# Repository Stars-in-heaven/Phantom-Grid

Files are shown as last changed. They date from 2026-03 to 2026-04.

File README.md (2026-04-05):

# PHANTOM GRID

> *Offline-first. Air-gapped. Encrypted. Built for the field.*

Phantom Grid is a series of purpose-built handheld devices engineered for those who operate outside the comfort of connectivity. No Wi-Fi. No cloud sync. No IP assignment. Every hardware and firmware decision is governed by a single principle: **security first, convenience never.**

https://phantom-grid.netlify.app - our site :0 **( has some issues/WIP cuz I keep running out of Netlify credit )**

---

## Series

| ID | Name | Description |
|----|---|---|
| **S** | Survival | Bare minimum. Maximum efficiency. Built to run when nothing else does. |
| **T** | Tactical | Feature-packed, encrypted, hardened. Heavy-duty field use. |
| **X** | Experimental | Highly specialised. Each unit unique. Not for general deployment. |
| **C** | Cyber | Fully off-grid. Offensive posture. Maximum resource load. |

---

## Current Build — T-V.1

The first Tactical series device. Dual-panel, hinged form factor with three independent displays, local sensor data, GPS, and an air-gapped file archive terminal.

### Architecture

- **Dual ESP32-C6 SuperMini** — one per side, connected via 4-wire UART hinge link
- **Left side** — Tactical Overwatch Panel (OLEDs, 5-way nav, GPS, moisture, battery)
- **Right side** — Archive Command Terminal (ILI9341 TFT, microSD, tactile buttons)
- **Power** — LiPo 2000–2500mAh → TP4056 (dual protection) → 3.3V buck converter → shared rail via hinge

### Displays

| Display | Role | Interface |
|---|---|---|
| 0.91" OLED 128×32 | Battery, time, date | I²C |
| 1.5" OLED 128×128 | GPS, moisture, sensor data | I²C via TCA9548A |
| 2.4" TFT ILI9341 | File browser, archive terminal | SPI |

### Storage

Files are loaded onto the microSD card by **physically removing it**, writing via USB adapter on a separate machine, and reinserting. No cloud sync. No Wi-Fi. No detectable radio signature. By design.

---

## Build Phases

- [x] **Phase 1** — Architecture & Pinout
- [x] **Phase 2** — Breadboard Prototype
- [ ] **Phase 3** — Firmware Foundation
- [x] **Phase 4** — Feature Layer
- [ ] **Phase 5** — Firmware Hardening
- [ ] **Phase 6** — Physical Build

 (working on getting the components to build the first
  prototype to begin firmware)

---

## Firmware Protection (Phase 5)

- Strip all debug symbols, aggressive optimisation (`-O2/-O3`)
- Obfuscator-LLVM control flow mangling
- CRC/hash self-check on boot — halts if tampered
- Chip ID binding — binds to first chip it runs on, cloning breaks it
- Sensitive logic derived at runtime, never stored plainly in binary
- Binary-only distribution with checksum and signature

---

## Repository Structure

```
phantom-grid/
├── Enclosure/               # Case 3d model
│   ├── Enclosure.f3d
│   ├── Enclosure.step
│   └── Enclosure.stl
|
├── PCBs/               # Kicad PCB files
│   ├── left side/
|   |    ├── left_side.kicad_pcb
|   |    ├── left_side.kicad_pro
|   |    └── left_side.kicad_sch
|   |
│   └── right side/
|       ├── right.kicad_pcb
|       ├── right.kicad_pro
|       └── right.kicad_sch
|  
├── .gitignore
├── README.md    
└── LICENSE

```

---

## Estimated Build Cost

**~£43–80** depending on component sourcing. All parts sourced from AliExpress. Full BOM available in `site/bom.html`.

---

## Progress --  T-V.1

### Left side ( Tactical over-watch Panel )
| Schematic | PCB | 3d-view  |
| --- |:---:| -----:|
|  |  |  |

### Right side ( Archive Terminal Panel )
| Schematic | PCB | 3d-view  |
| --- |:---:| -----:|
|  |  |  |

### ENCLOSURE:
 (It is split in half, but due to this being a prototype it has no screw holes, As I plan to drill them in for testing sizes and such. And then in more final models it will advance to having screw holes.)

---

## Licensing

This project uses a dual licensing model:

| What | Licence | Details |
|---|---|---|
| PCB files, enclosure, skeleton firmware | **CERN-OHL-S v2** | Open hardware — modifications must be released under the same licence |
| Full feature firmware | **Proprietary** | Never released — binary only, chip-bound, encrypted |

The open skeleton gives you everything you need to understand how the device is wired and structured. The full firmware with all features ships only with commercially built units and is protected by hardware-level encryption and chip binding. You are free to build your own version using the open source materials — you cannot take the commercial firmware.

---

*PG-T-V.1 / REV.002 / ENCRYPTED / AIR-GAPPED*

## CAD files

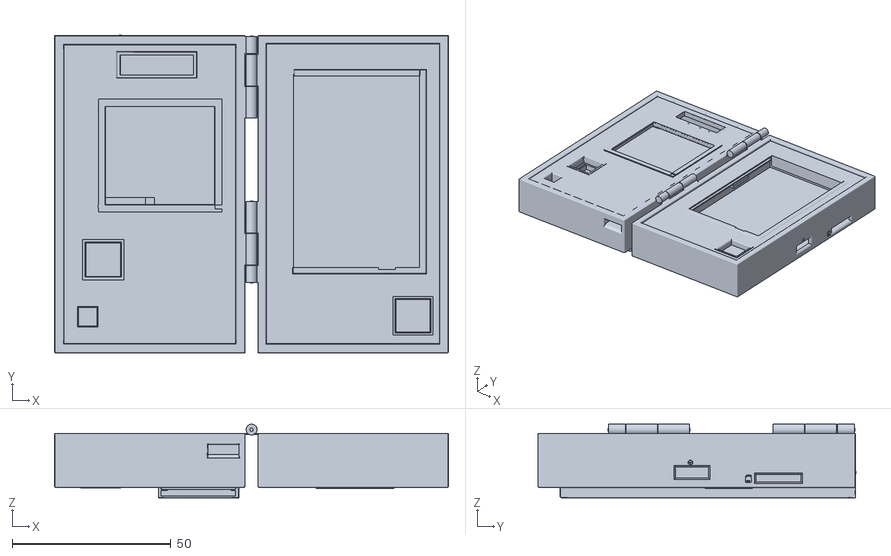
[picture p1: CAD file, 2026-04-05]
Enclosure/Enclosure.stl
124.0 x 100.1 x 23.2

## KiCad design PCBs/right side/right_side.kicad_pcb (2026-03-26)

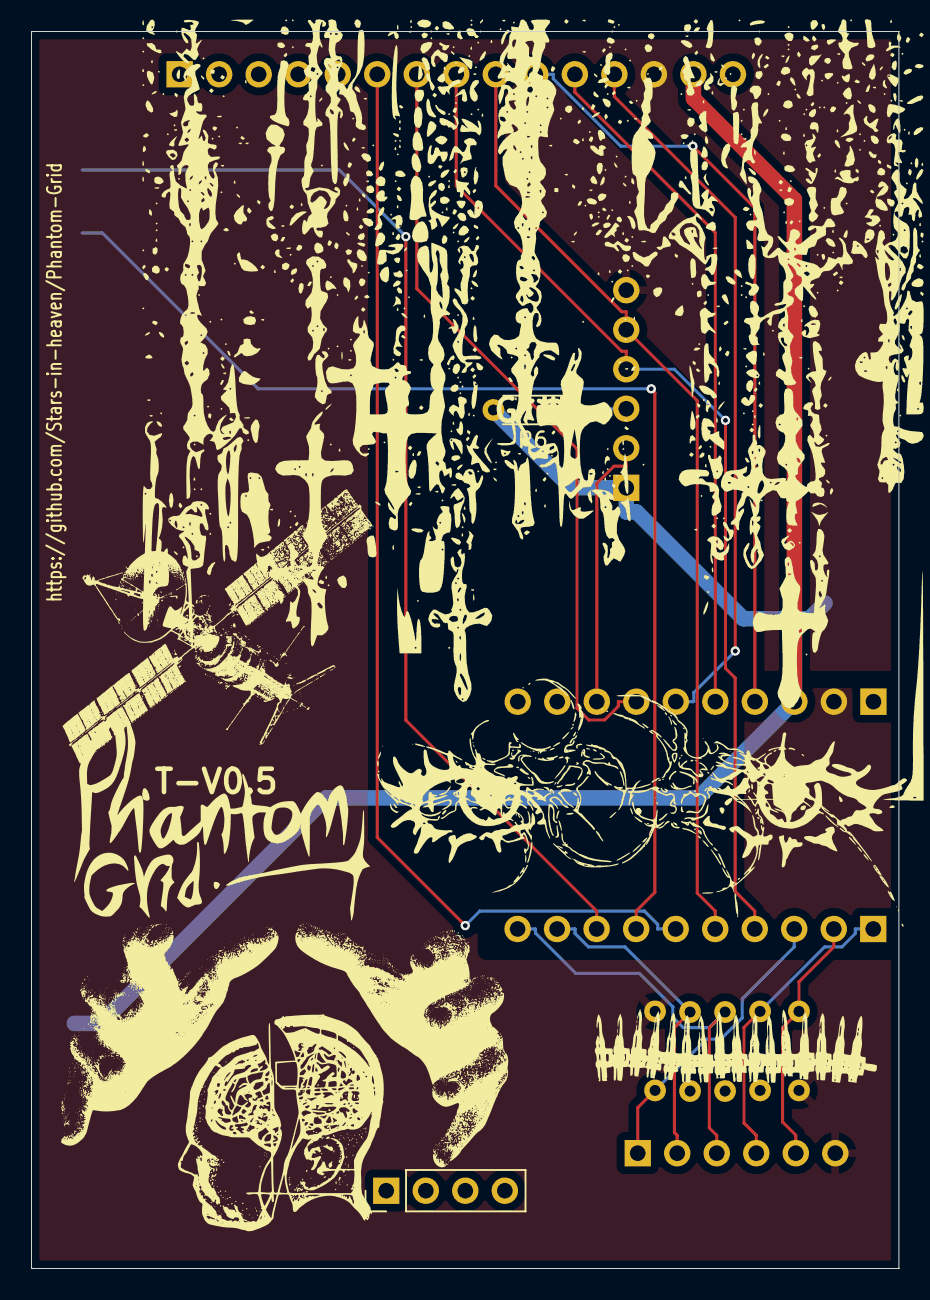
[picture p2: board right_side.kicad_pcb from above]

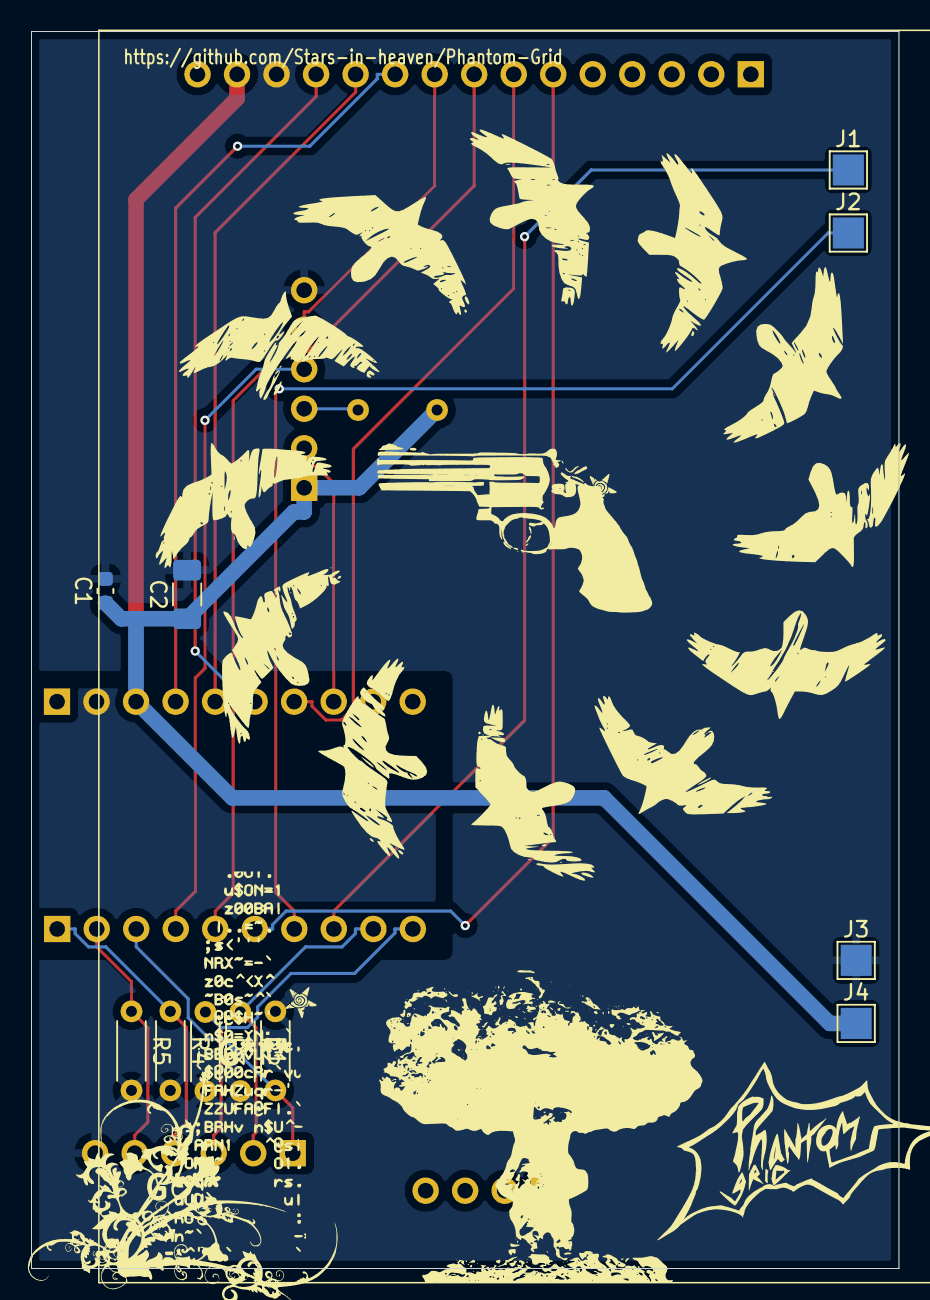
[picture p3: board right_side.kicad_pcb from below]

Board: 2 copper layers, 55.8 x 79.5 mm, 18 parts (13 on the bottom side), 18 nets.

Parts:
5-way_nav1: 5 way
.: LOGO
C1: 100nF; C_0603_1608Metric
C2: 10uF; C_1206_3216Metric_Pad1.33x1.80mm_HandSolder
J1: TX HINGE; TestPoint_Pad_2.0x2.0mm
J2: RX HINGE; TestPoint_Pad_2.0x2.0mm
J3: GND HINGE; TestPoint_Pad_2.0x2.0mm
J4: 3V3 HINGE; TestPoint_Pad_2.0x2.0mm
J5: TFT screen; PinHeader_1x15_P2.54mm_Vertical
J7: SD READER; PinHeader_1x06_P2.54mm_Vertical
R1, R2, R3, R4, R5: 10k; R_Axial_DIN0204_L3.6mm_D1.6mm_P5.08mm_Horizontal
R6: 10K; R_Axial_DIN0204_L3.6mm_D1.6mm_P5.08mm_Horizontal
U1: ESP32-C6 MINI
logo 2: LOGO

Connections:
+3V3: C1.1, C2.1, J4.1, J5.14, J7.1, R6.2, U1.13 (3V3)
/HINGE_RX: J2.1, U1.7 (GPIO_04)
/HINGE_TX: J1.1, U1.8 (GPIO_05)
GND: 5-way_nav1.6 (gnd), C1.2, C2.2, J3.1, J5.13, J7.6, R1.2, R2.2, R3.2, R4.2, R5.2, U1.12 (GND)
SD_CS: J7.2, U1.18 (GPIO_10)
SD_MISO: J7.3, R6.1
TFT_CLK: J5.8, J7.4, U1.4 (GPIO_01)
TFT_CS: J5.12, U1.16 (GPIO_21)
TFT_DC: J5.10, U1.14 (GPIO_19)
TFT_LED: J5.7, U1.17 (GPIO_22)
TFT_MISO: J5.6, U1.6 (GPIO_03)
TFT_MOSI: J5.9, J7.5, U1.5 (GPIO_02)
TFT_RST: J5.11, U1.15 (GPIO_20)
back_1: 5-way_nav1.2 (back), R2.1, U1.9 (GPIO_06)
forward_1: 5-way_nav1.1 (forward), R1.1, U1.3 (GPIO_00)
left_1: 5-way_nav1.3 (left), R3.1, U1.10 (GPIO_07)
middle_1: 5-way_nav1.5 (m), R5.1, U1.2 (RX)
right_1: 5-way_nav1.4 (right), R4.1, U1.1 (TX)

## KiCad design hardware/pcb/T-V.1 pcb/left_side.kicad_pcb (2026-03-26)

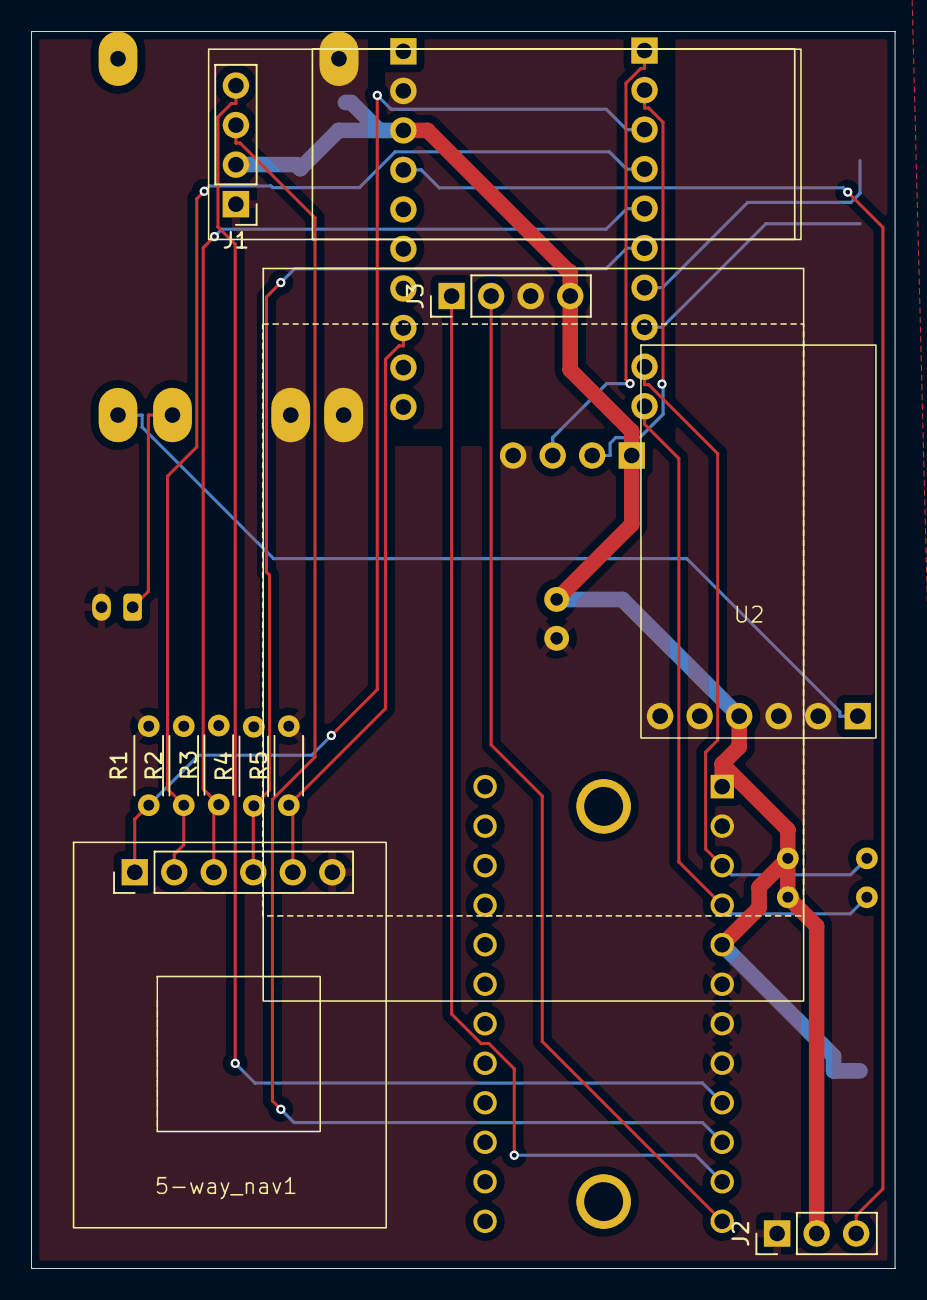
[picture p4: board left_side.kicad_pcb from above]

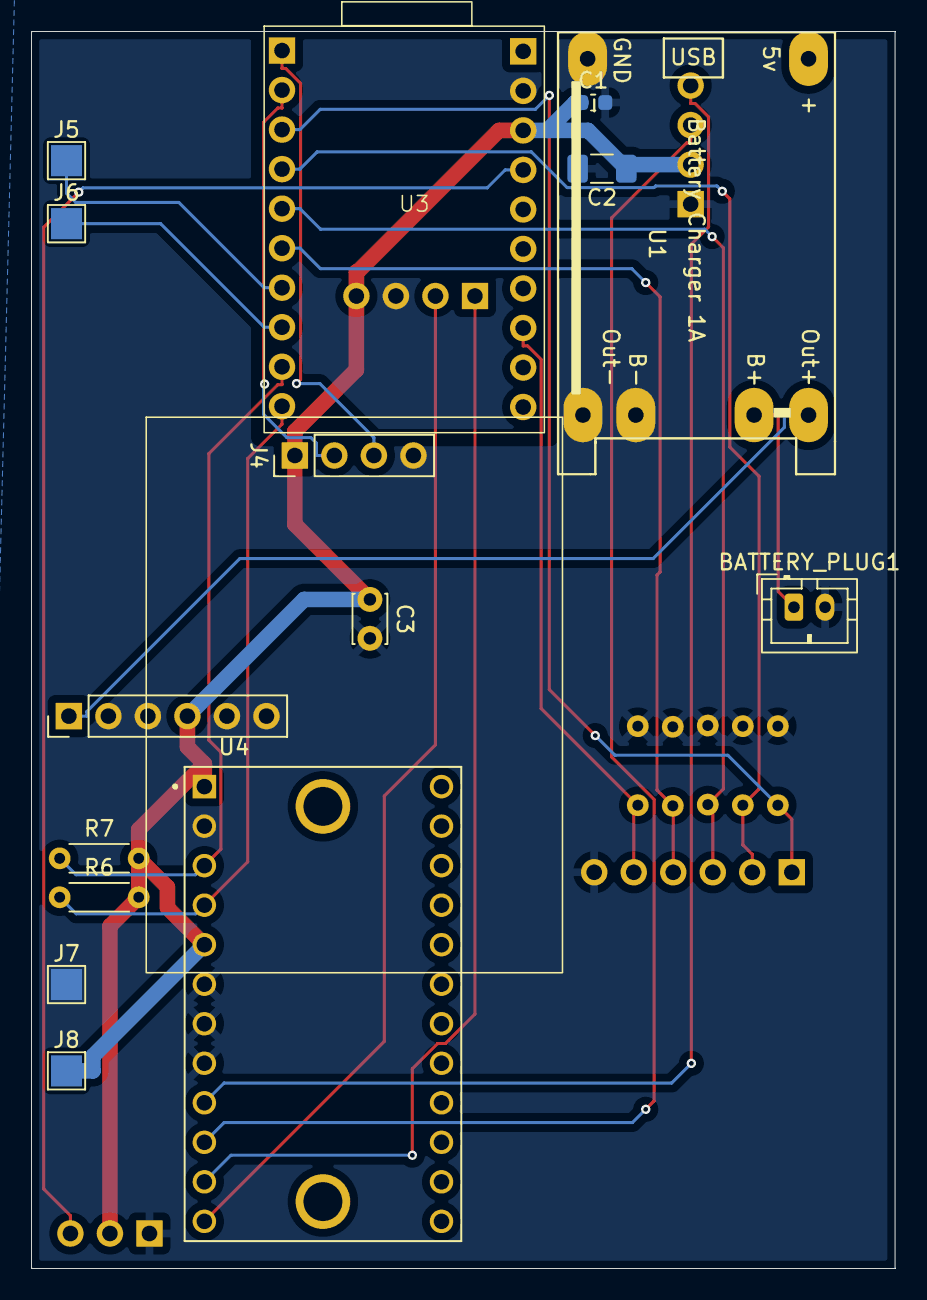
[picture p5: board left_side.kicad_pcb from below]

Board: 2 copper layers, 55.5 x 79.5 mm, 24 parts (14 on the bottom side), 20 nets.

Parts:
5-way_nav1: 5 way
BATTERY_PLUG1: B2B-PH-K-S_LF__SN_; JST_PH_B2B-PH-K_1x02_P2.00mm_Vertical
C1: 100nF; C_0603_1608Metric
C2: 10uF; C_1206_3216Metric_Pad1.33x1.80mm_HandSolder
C3: 100nF; C_Disc_D3.0mm_W2.0mm_P2.50mm
J1: MINI oled; PinHeader_1x04_P2.54mm_Vertical
J2: Moisture sensor; PinHeader_1x03_P2.54mm_Vertical
J3: MAIN oled; PinHeader_1x04_P2.54mm_Vertical
J4: GPS; PinHeader_1x04_P2.54mm_Vertical
J5: TX HINGE; TestPoint_Pad_2.0x2.0mm
J6: RX HINGE; TestPoint_Pad_2.0x2.0mm
J7: GND HINGE; TestPoint_Pad_2.0x2.0mm
J8: 3V3 HINGE; TestPoint_Pad_2.0x2.0mm
R1, R2, R3, R4, R5: 10k; R_Axial_DIN0204_L3.6mm_D1.6mm_P5.08mm_Horizontal
R6, R7: 4.7k; R_Axial_DIN0204_L3.6mm_D1.6mm_P5.08mm_Horizontal
U1: tp4056
U2: buck converter
U3: ESP32-C6 MINI
U4: 2717; MODULE_2717

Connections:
+3V3: C1.1, C2.1, C3.1, J1.2, J2.2, J3.4, J4.1, J8.1, R6.2, R7.2, U2.4 (OUT+), U3.13 (3V3), U4.1 (VIN), U4.5 (RST)
/HINGE_RX: J6.1, U3.8 (GPIO_05)
/HINGE_TX: J5.1, U3.7 (GPIO_04)
GND: 5-way_nav1.6 (gnd), BATTERY_PLUG1.2 (B-), C1.2, C2.2, C3.2, J1.1, J2.1, J3.3, J4.4, J7.1, R1.2, R2.2, R3.2, R4.2, R5.2, U1.2 (IN-), U1.4 (B-), U1.6 (O-), U2.2 (IN-), U2.3 (GND), U2.5 (OUT-), U2.6 (GND2), U3.12 (GND), U4.2 (GND), U4.6 (A0), U4.7 (A1), U4.8 (A2)
Moisture sensor: J2.3, U3.14 (GPIO_19)
unnamed: BATTERY_PLUG1.1 (B+), U1.3 (B+)
unnamed: U1.5 (O+), U2.1 (IN+)
RX: J4.2, U3.2 (RX)
SC0: J1.3, U4.10 (SCL0)
SC1: J3.2, U4.12 (SCL1)
SCL: R6.1, U3.10 (GPIO_07), U4.4 (SCL)
SD0: J1.4, U4.9 (SDA0)
SD1: J3.1 (SDA), U4.11 (SDA1)
SDA: R7.1, U3.9 (GPIO_06), U4.3 (SDA)
TX: J4.3, U3.1 (TX)
back: 5-way_nav1.2 (back), R2.1, U3.4 (GPIO_01)
forward: 5-way_nav1.1 (forward), R1.1, U3.3 (GPIO_00)
left: 5-way_nav1.3 (left), R3.1, U3.5 (GPIO_02)
middle: 5-way_nav1.5 (m), R5.1, U3.18 (GPIO_10)
right: 5-way_nav1.4 (right), R4.1, U3.6 (GPIO_03)

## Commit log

2026-03-03 Revise README for Phantom Grid project details
    Expanded the README to provide detailed information about the Phantom Grid project, including device architecture, build phases, firmware protection, repository structure, estimated build cost, and l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
2026-03-03 Initial commit — add structure, site files, docs and licence
2026-03-03 Add .gitignore — remove .DS_Store
2026-03-04 made buttons open in a new tab instead of in the same tab
    cuz im too lazy to add back buttons
2026-03-26 Update Phantom-Grid
    [left_side.kicad_pcb, left_side.kicad_sch, right_side.kicad_pcb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]
2026-03-26 Revise README with sensor data and progress details
    Updated sensor data description and added progress section.
2026-03-26 Update README to include enclosure section
    Added enclosure section with an image to the README.
2026-03-26 Updating PCB files :P
    [right_side.kicad_pcb]
2026-03-26 Update enclosure image and prototype details
    Updated the enclosure image and added a note about screw holes in the prototype.
2026-03-26 Add enclosure files
    [right_side.kicad_pcb]
2026-04-05 Updated structure
    [Enclosure.stl, left_side.kicad_sch, right_side.kicad_pcb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]
